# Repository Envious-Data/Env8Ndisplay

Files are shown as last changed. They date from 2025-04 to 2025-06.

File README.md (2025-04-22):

# Env8Ndisplay
 A 40x7 display using x4 is37fl3130

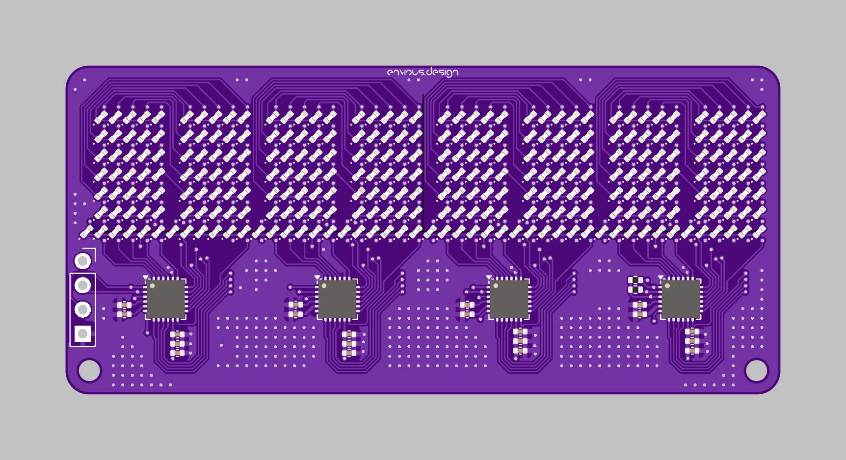
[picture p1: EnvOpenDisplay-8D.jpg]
Hello


## Info:
I designed a clock a while ago using 8x LTP-305s, LTP-305s and TIL-305s are both discontinued but I made a PCBA replica called DIY305, Ive also just put LEDs on a PCB in the same arangement which this repo is one of them.

I quite like character displays which is why I made this one, there is some demo code in the firmware folder that makes use of the pico SDK so wire it up to the a pico making sure VCC goes to 3V3 and not VBUS or VSYS unless you want to use a level shifter, a number of ICs can handle different logic level voltage if needed but this one tends to glitch out in my experience.

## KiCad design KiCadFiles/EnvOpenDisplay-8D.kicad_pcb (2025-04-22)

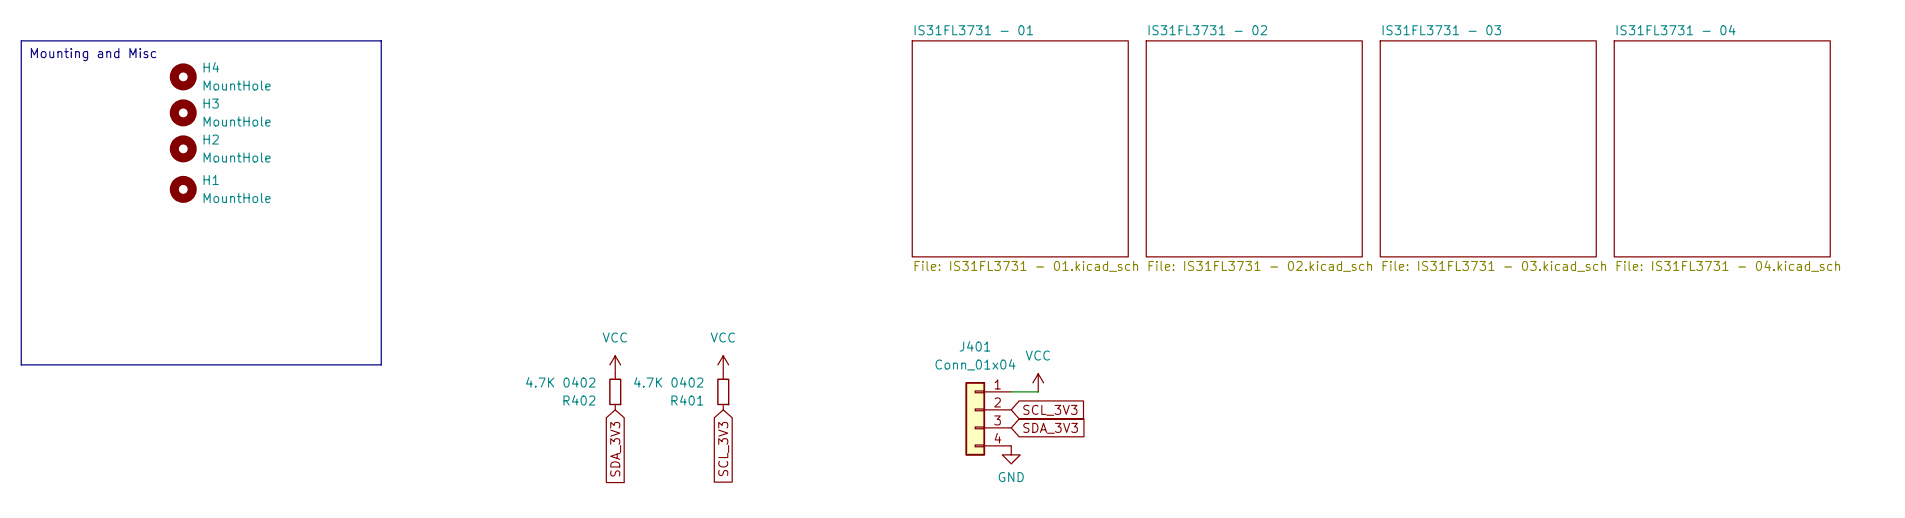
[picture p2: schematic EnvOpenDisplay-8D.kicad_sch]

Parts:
H1, H2, H3, H4: MountHole; MountingHole_2.2mm_M2
J401: Conn_01x04; PinSocket_1x04_P2.54mm_Vertical
R401, R402: 4.7K 0402; R_0402_1005Metric

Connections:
GND: J401.4; also elsewhere on the board
SCL_3V3: J401.2, R401.1; also elsewhere on the board
SDA_3V3: J401.3, R402.1; also elsewhere on the board
VCC: J401.1, R401.2, R402.2; also elsewhere on the board

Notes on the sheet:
Mounting and Misc

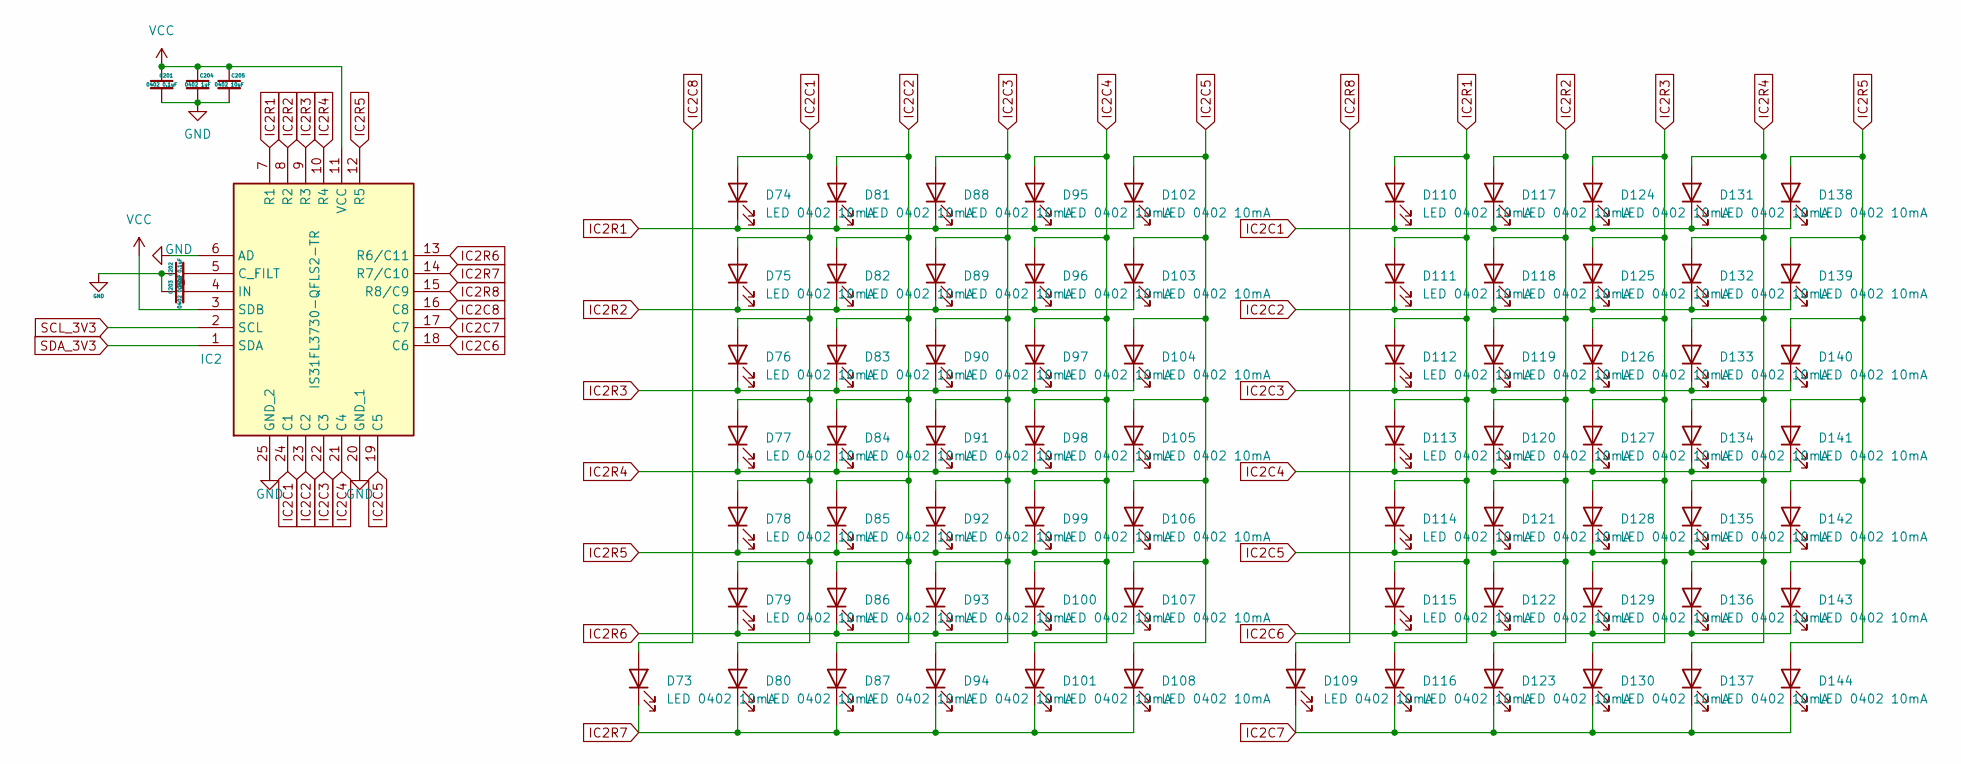
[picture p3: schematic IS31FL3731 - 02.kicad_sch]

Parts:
C201, C202: 0402 0.1uF; C_0402_1005Metric
C203: 0402 0.22uF; C_0402_1005Metric
C204: 0402 1uF; C_0402_1005Metric
C205: 0402 10uF; C_0402_1005Metric
D73, D74, D75, D76, D77, D78, D79, D80, D81, D82, D83, D84, D85, D86, D87, D88, D89, D90, D91, D92, D93, D94, D95, D96, D97, D98, D99, D100, D101, D102, D103, D104, D105, D106, D107, D108, D109, D110, D111, D112, D113, D114, D115, D116, D117, D118, D119, D120, D121, D122, D123, D124, D125, D126, D127, D128, D129, D130, D131, D132, D133, D134, D135, D136, D137, D138, D139, D140, D141, D142, D143, D144: LED 0402 10mA; LED_0402_1005Metric
IC2: IS31FL3730-QFLS2-TR; QFN-24-1EP_4x4mm_P0.5mm_EP2.6x2.6mm_ThermalVias; Mouser Part Number 870-IS31FL3730QFLS2R

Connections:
GND: C201.2, C202.1, C203.1, C204.2, C205.2, IC2.6 (AD), IC2.20 (GND_1), IC2.25 (GND_2); also elsewhere on the board
IC2C1: D74.2 (A), D75.2 (A), D76.2 (A), D77.2 (A), D78.2 (A), D79.2 (A), D80.2 (A), D110.1 (K), D117.1 (K), D124.1 (K), D131.1 (K), D138.1 (K), IC2.24 (C1)
IC2C2: D81.2 (A), D82.2 (A), D83.2 (A), D84.2 (A), D85.2 (A), D86.2 (A), D87.2 (A), D111.1 (K), D118.1 (K), D125.1 (K), D132.1 (K), D139.1 (K), IC2.23 (C2)
IC2C3: D88.2 (A), D89.2 (A), D90.2 (A), D91.2 (A), D92.2 (A), D93.2 (A), D94.2 (A), D112.1 (K), D119.1 (K), D126.1 (K), D133.1 (K), D140.1 (K), IC2.22 (C3)
IC2C4: D95.2 (A), D96.2 (A), D97.2 (A), D98.2 (A), D99.2 (A), D100.2 (A), D101.2 (A), D113.1 (K), D120.1 (K), D127.1 (K), D134.1 (K), D141.1 (K), IC2.21 (C4)
IC2C5: D102.2 (A), D103.2 (A), D104.2 (A), D105.2 (A), D106.2 (A), D107.2 (A), D108.2 (A), D114.1 (K), D121.1 (K), D128.1 (K), D135.1 (K), D142.1 (K), IC2.19 (C5)
IC2C6: D115.1 (K), D122.1 (K), D129.1 (K), D136.1 (K), D143.1 (K), IC2.18 (C6)
IC2C7: D109.1 (K), D116.1 (K), D123.1 (K), D130.1 (K), D137.1 (K), D144.1 (K), IC2.17 (C7)
IC2C8: D73.2 (A), IC2.16 (C8)
IC2R1: D74.1 (K), D81.1 (K), D88.1 (K), D95.1 (K), D102.1 (K), D110.2 (A), D111.2 (A), D112.2 (A), D113.2 (A), D114.2 (A), D115.2 (A), D116.2 (A), IC2.7 (R1)
IC2R2: D75.1 (K), D82.1 (K), D89.1 (K), D96.1 (K), D103.1 (K), D117.2 (A), D118.2 (A), D119.2 (A), D120.2 (A), D121.2 (A), D122.2 (A), D123.2 (A), IC2.8 (R2)
IC2R3: D76.1 (K), D83.1 (K), D90.1 (K), D97.1 (K), D104.1 (K), D124.2 (A), D125.2 (A), D126.2 (A), D127.2 (A), D128.2 (A), D129.2 (A), D130.2 (A), IC2.9 (R3)
IC2R4: D77.1 (K), D84.1 (K), D91.1 (K), D98.1 (K), D105.1 (K), D131.2 (A), D132.2 (A), D133.2 (A), D134.2 (A), D135.2 (A), D136.2 (A), D137.2 (A), IC2.10 (R4)
IC2R5: D78.1 (K), D85.1 (K), D92.1 (K), D99.1 (K), D106.1 (K), D138.2 (A), D139.2 (A), D140.2 (A), D141.2 (A), D142.2 (A), D143.2 (A), D144.2 (A), IC2.12 (R5)
IC2R6: D79.1 (K), D86.1 (K), D93.1 (K), D100.1 (K), D107.1 (K), IC2.13 (R6/C11)
IC2R7: D73.1 (K), D80.1 (K), D87.1 (K), D94.1 (K), D101.1 (K), D108.1 (K), IC2.14 (R7/C10)
IC2R8: D109.2 (A), IC2.15 (R8/C9)
unnamed: C202.2, IC2.5 (C_FILT)
unnamed: C203.2, IC2.4 (IN)
SCL_3V3: IC2.2 (SCL); also elsewhere on the board
SDA_3V3: IC2.1 (SDA); also elsewhere on the board
VCC: C201.1, C204.1, C205.1, IC2.3 (SDB), IC2.11 (VCC); also elsewhere on the board

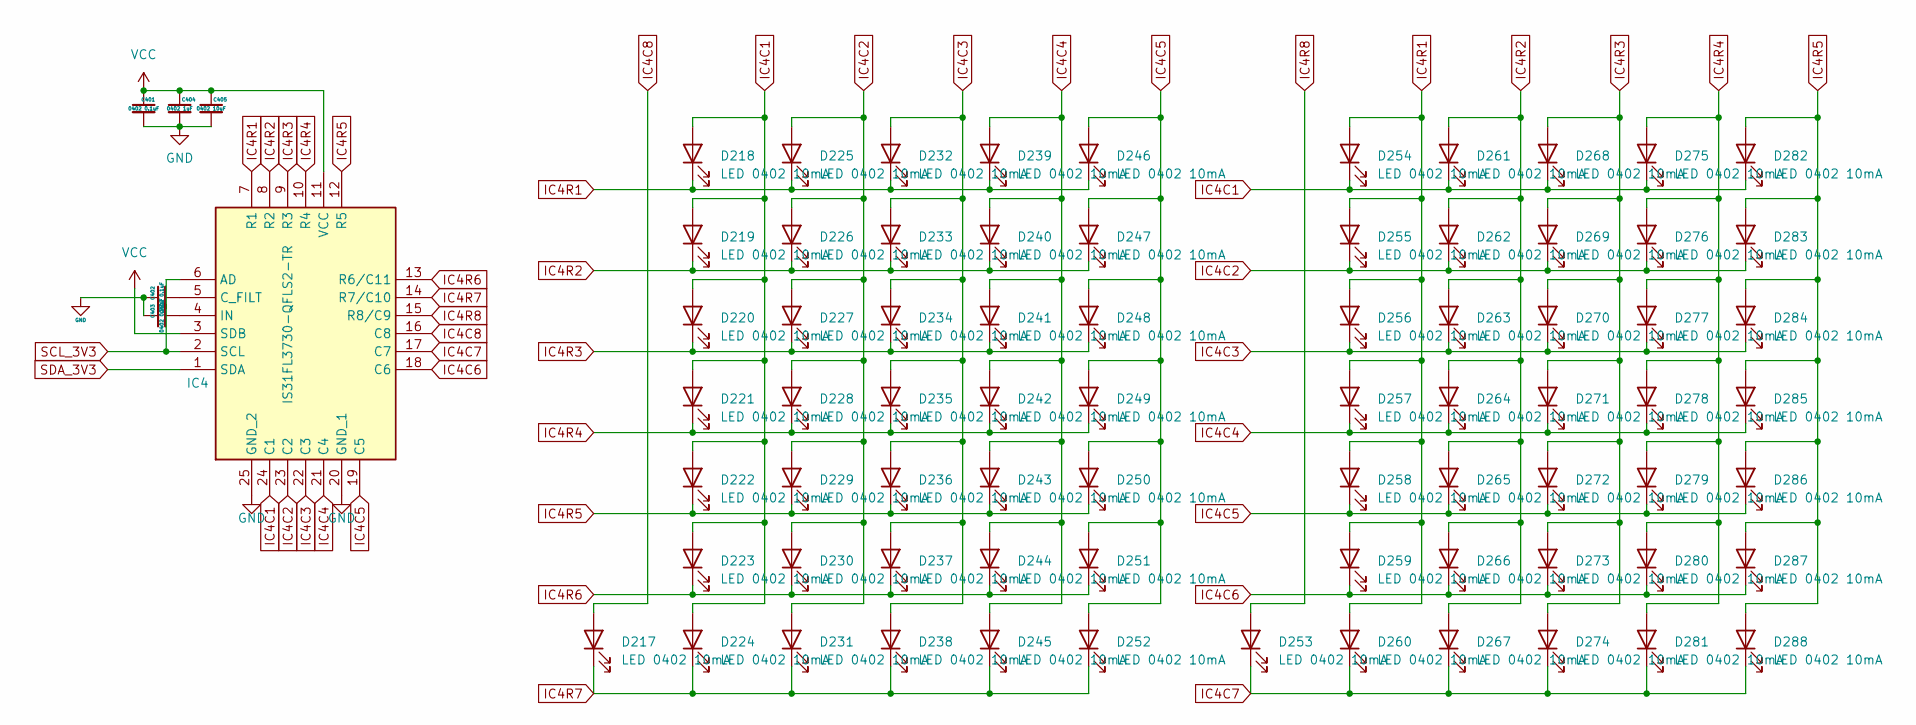
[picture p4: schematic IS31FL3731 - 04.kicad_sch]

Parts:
C401, C402: 0402 0.1uF; C_0402_1005Metric
C403: 0402 0.22uF; C_0402_1005Metric
C404: 0402 1uF; C_0402_1005Metric
C405: 0402 10uF; C_0402_1005Metric
D217, D218, D219, D220, D221, D222, D223, D224, D225, D226, D227, D228, D229, D230, D231, D232, D233, D234, D235, D236, D237, D238, D239, D240, D241, D242, D243, D244, D245, D246, D247, D248, D249, D250, D251, D252, D253, D254, D255, D256, D257, D258, D259, D260, D261, D262, D263, D264, D265, D266, D267, D268, D269, D270, D271, D272, D273, D274, D275, D276, D277, D278, D279, D280, D281, D282, D283, D284, D285, D286, D287, D288: LED 0402 10mA; LED_0402_1005Metric
IC4: IS31FL3730-QFLS2-TR; QFN-24-1EP_4x4mm_P0.5mm_EP2.6x2.6mm_ThermalVias; Mouser Part Number 870-IS31FL3730QFLS2R

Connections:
GND: C401.2, C402.1, C403.1, C404.2, C405.2, IC4.20 (GND_1), IC4.25 (GND_2); also elsewhere on the board
IC4C1: D218.2 (A), D219.2 (A), D220.2 (A), D221.2 (A), D222.2 (A), D223.2 (A), D224.2 (A), D254.1 (K), D261.1 (K), D268.1 (K), D275.1 (K), D282.1 (K), IC4.24 (C1)
IC4C2: D225.2 (A), D226.2 (A), D227.2 (A), D228.2 (A), D229.2 (A), D230.2 (A), D231.2 (A), D255.1 (K), D262.1 (K), D269.1 (K), D276.1 (K), D283.1 (K), IC4.23 (C2)
IC4C3: D232.2 (A), D233.2 (A), D234.2 (A), D235.2 (A), D236.2 (A), D237.2 (A), D238.2 (A), D256.1 (K), D263.1 (K), D270.1 (K), D277.1 (K), D284.1 (K), IC4.22 (C3)
IC4C4: D239.2 (A), D240.2 (A), D241.2 (A), D242.2 (A), D243.2 (A), D244.2 (A), D245.2 (A), D257.1 (K), D264.1 (K), D271.1 (K), D278.1 (K), D285.1 (K), IC4.21 (C4)
IC4C5: D246.2 (A), D247.2 (A), D248.2 (A), D249.2 (A), D250.2 (A), D251.2 (A), D252.2 (A), D258.1 (K), D265.1 (K), D272.1 (K), D279.1 (K), D286.1 (K), IC4.19 (C5)
IC4C6: D259.1 (K), D266.1 (K), D273.1 (K), D280.1 (K), D287.1 (K), IC4.18 (C6)
IC4C7: D253.1 (K), D260.1 (K), D267.1 (K), D274.1 (K), D281.1 (K), D288.1 (K), IC4.17 (C7)
IC4C8: D217.2 (A), IC4.16 (C8)
IC4R1: D218.1 (K), D225.1 (K), D232.1 (K), D239.1 (K), D246.1 (K), D254.2 (A), D255.2 (A), D256.2 (A), D257.2 (A), D258.2 (A), D259.2 (A), D260.2 (A), IC4.7 (R1)
IC4R2: D219.1 (K), D226.1 (K), D233.1 (K), D240.1 (K), D247.1 (K), D261.2 (A), D262.2 (A), D263.2 (A), D264.2 (A), D265.2 (A), D266.2 (A), D267.2 (A), IC4.8 (R2)
IC4R3: D220.1 (K), D227.1 (K), D234.1 (K), D241.1 (K), D248.1 (K), D268.2 (A), D269.2 (A), D270.2 (A), D271.2 (A), D272.2 (A), D273.2 (A), D274.2 (A), IC4.9 (R3)
IC4R4: D221.1 (K), D228.1 (K), D235.1 (K), D242.1 (K), D249.1 (K), D275.2 (A), D276.2 (A), D277.2 (A), D278.2 (A), D279.2 (A), D280.2 (A), D281.2 (A), IC4.10 (R4)
IC4R5: D222.1 (K), D229.1 (K), D236.1 (K), D243.1 (K), D250.1 (K), D282.2 (A), D283.2 (A), D284.2 (A), D285.2 (A), D286.2 (A), D287.2 (A), D288.2 (A), IC4.12 (R5)
IC4R6: D223.1 (K), D230.1 (K), D237.1 (K), D244.1 (K), D251.1 (K), IC4.13 (R6/C11)
IC4R7: D217.1 (K), D224.1 (K), D231.1 (K), D238.1 (K), D245.1 (K), D252.1 (K), IC4.14 (R7/C10)
IC4R8: D253.2 (A), IC4.15 (R8/C9)
unnamed: C402.2, IC4.5 (C_FILT)
unnamed: C403.2, IC4.4 (IN)
SCL_3V3: IC4.2 (SCL), IC4.6 (AD); also elsewhere on the board
SDA_3V3: IC4.1 (SDA); also elsewhere on the board
VCC: C401.1, C404.1, C405.1, IC4.3 (SDB), IC4.11 (VCC); also elsewhere on the board

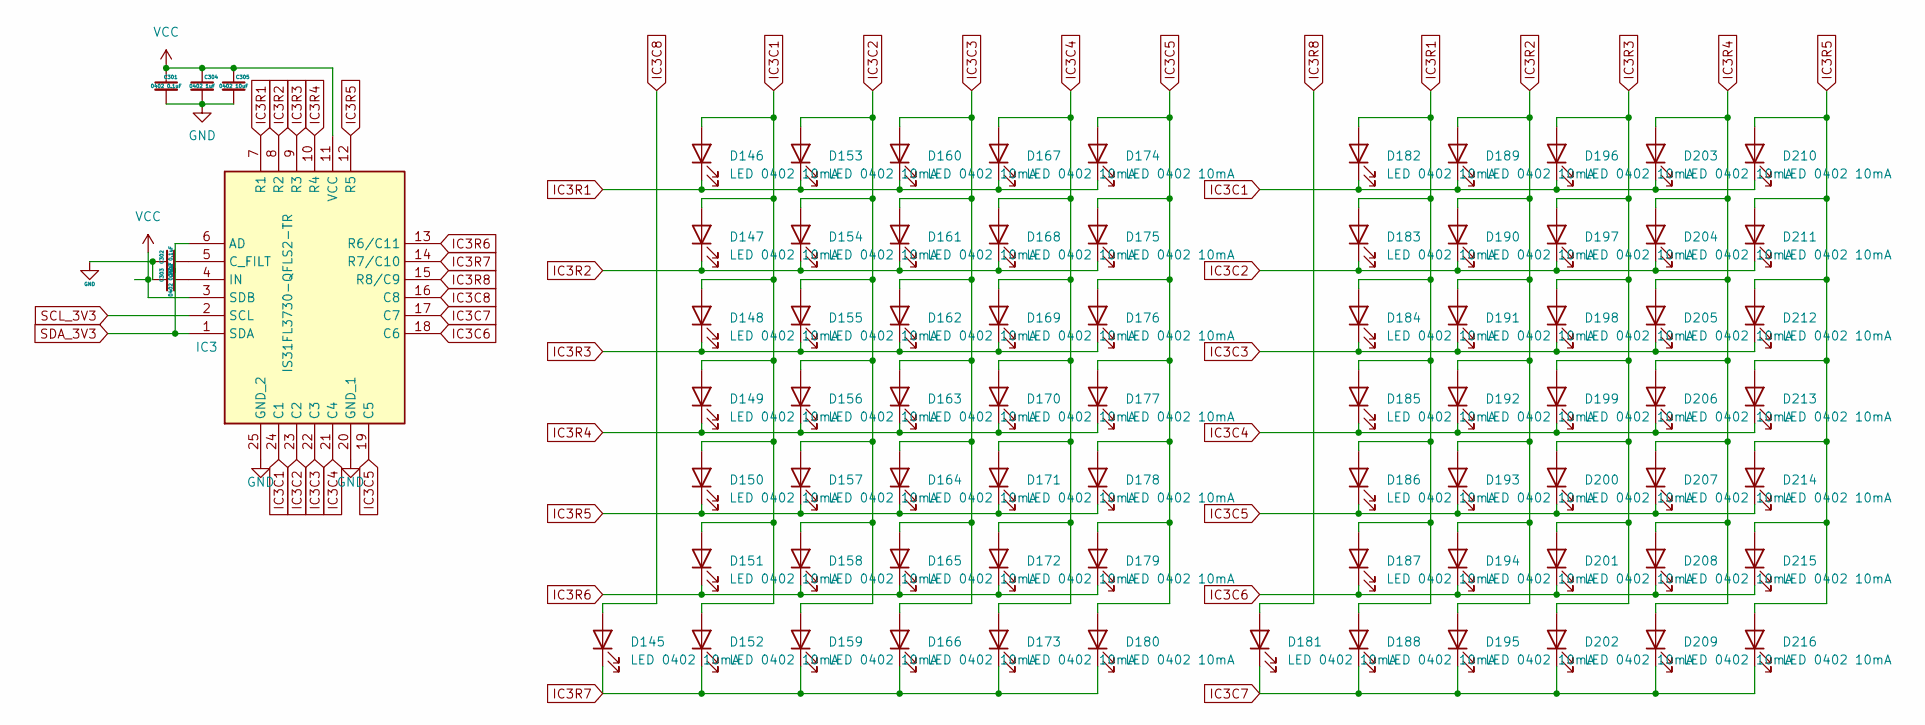
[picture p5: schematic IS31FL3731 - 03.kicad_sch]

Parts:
C301, C302: 0402 0.1uF; C_0402_1005Metric
C303: 0402 0.22uF; C_0402_1005Metric
C304: 0402 1uF; C_0402_1005Metric
C305: 0402 10uF; C_0402_1005Metric
D145, D146, D147, D148, D149, D150, D151, D152, D153, D154, D155, D156, D157, D158, D159, D160, D161, D162, D163, D164, D165, D166, D167, D168, D169, D170, D171, D172, D173, D174, D175, D176, D177, D178, D179, D180, D181, D182, D183, D184, D185, D186, D187, D188, D189, D190, D191, D192, D193, D194, D195, D196, D197, D198, D199, D200, D201, D202, D203, D204, D205, D206, D207, D208, D209, D210, D211, D212, D213, D214, D215, D216: LED 0402 10mA; LED_0402_1005Metric
IC3: IS31FL3730-QFLS2-TR; QFN-24-1EP_4x4mm_P0.5mm_EP2.6x2.6mm_ThermalVias; Mouser Part Number 870-IS31FL3730QFLS2R

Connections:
GND: C301.2, C302.1, C303.1, C304.2, C305.2, IC3.20 (GND_1), IC3.25 (GND_2); also elsewhere on the board
IC3C1: D146.2 (A), D147.2 (A), D148.2 (A), D149.2 (A), D150.2 (A), D151.2 (A), D152.2 (A), D182.1 (K), D189.1 (K), D196.1 (K), D203.1 (K), D210.1 (K), IC3.24 (C1)
IC3C2: D153.2 (A), D154.2 (A), D155.2 (A), D156.2 (A), D157.2 (A), D158.2 (A), D159.2 (A), D183.1 (K), D190.1 (K), D197.1 (K), D204.1 (K), D211.1 (K), IC3.23 (C2)
IC3C3: D160.2 (A), D161.2 (A), D162.2 (A), D163.2 (A), D164.2 (A), D165.2 (A), D166.2 (A), D184.1 (K), D191.1 (K), D198.1 (K), D205.1 (K), D212.1 (K), IC3.22 (C3)
IC3C4: D167.2 (A), D168.2 (A), D169.2 (A), D170.2 (A), D171.2 (A), D172.2 (A), D173.2 (A), D185.1 (K), D192.1 (K), D199.1 (K), D206.1 (K), D213.1 (K), IC3.21 (C4)
IC3C5: D174.2 (A), D175.2 (A), D176.2 (A), D177.2 (A), D178.2 (A), D179.2 (A), D180.2 (A), D186.1 (K), D193.1 (K), D200.1 (K), D207.1 (K), D214.1 (K), IC3.19 (C5)
IC3C6: D187.1 (K), D194.1 (K), D201.1 (K), D208.1 (K), D215.1 (K), IC3.18 (C6)
IC3C7: D181.1 (K), D188.1 (K), D195.1 (K), D202.1 (K), D209.1 (K), D216.1 (K), IC3.17 (C7)
IC3C8: D145.2 (A), IC3.16 (C8)
IC3R1: D146.1 (K), D153.1 (K), D160.1 (K), D167.1 (K), D174.1 (K), D182.2 (A), D183.2 (A), D184.2 (A), D185.2 (A), D186.2 (A), D187.2 (A), D188.2 (A), IC3.7 (R1)
IC3R2: D147.1 (K), D154.1 (K), D161.1 (K), D168.1 (K), D175.1 (K), D189.2 (A), D190.2 (A), D191.2 (A), D192.2 (A), D193.2 (A), D194.2 (A), D195.2 (A), IC3.8 (R2)
IC3R3: D148.1 (K), D155.1 (K), D162.1 (K), D169.1 (K), D176.1 (K), D196.2 (A), D197.2 (A), D198.2 (A), D199.2 (A), D200.2 (A), D201.2 (A), D202.2 (A), IC3.9 (R3)
IC3R4: D149.1 (K), D156.1 (K), D163.1 (K), D170.1 (K), D177.1 (K), D203.2 (A), D204.2 (A), D205.2 (A), D206.2 (A), D207.2 (A), D208.2 (A), D209.2 (A), IC3.10 (R4)
IC3R5: D150.1 (K), D157.1 (K), D164.1 (K), D171.1 (K), D178.1 (K), D210.2 (A), D211.2 (A), D212.2 (A), D213.2 (A), D214.2 (A), D215.2 (A), D216.2 (A), IC3.12 (R5)
IC3R6: D151.1 (K), D158.1 (K), D165.1 (K), D172.1 (K), D179.1 (K), IC3.13 (R6/C11)
IC3R7: D145.1 (K), D152.1 (K), D159.1 (K), D166.1 (K), D173.1 (K), D180.1 (K), IC3.14 (R7/C10)
IC3R8: D181.2 (A), IC3.15 (R8/C9)
unnamed: C302.2, IC3.5 (C_FILT)
unnamed: C303.2, IC3.4 (IN)
SCL_3V3: IC3.2 (SCL); also elsewhere on the board
SDA_3V3: IC3.1 (SDA), IC3.6 (AD); also elsewhere on the board
VCC: C301.1, C304.1, C305.1, IC3.3 (SDB), IC3.11 (VCC); also elsewhere on the board

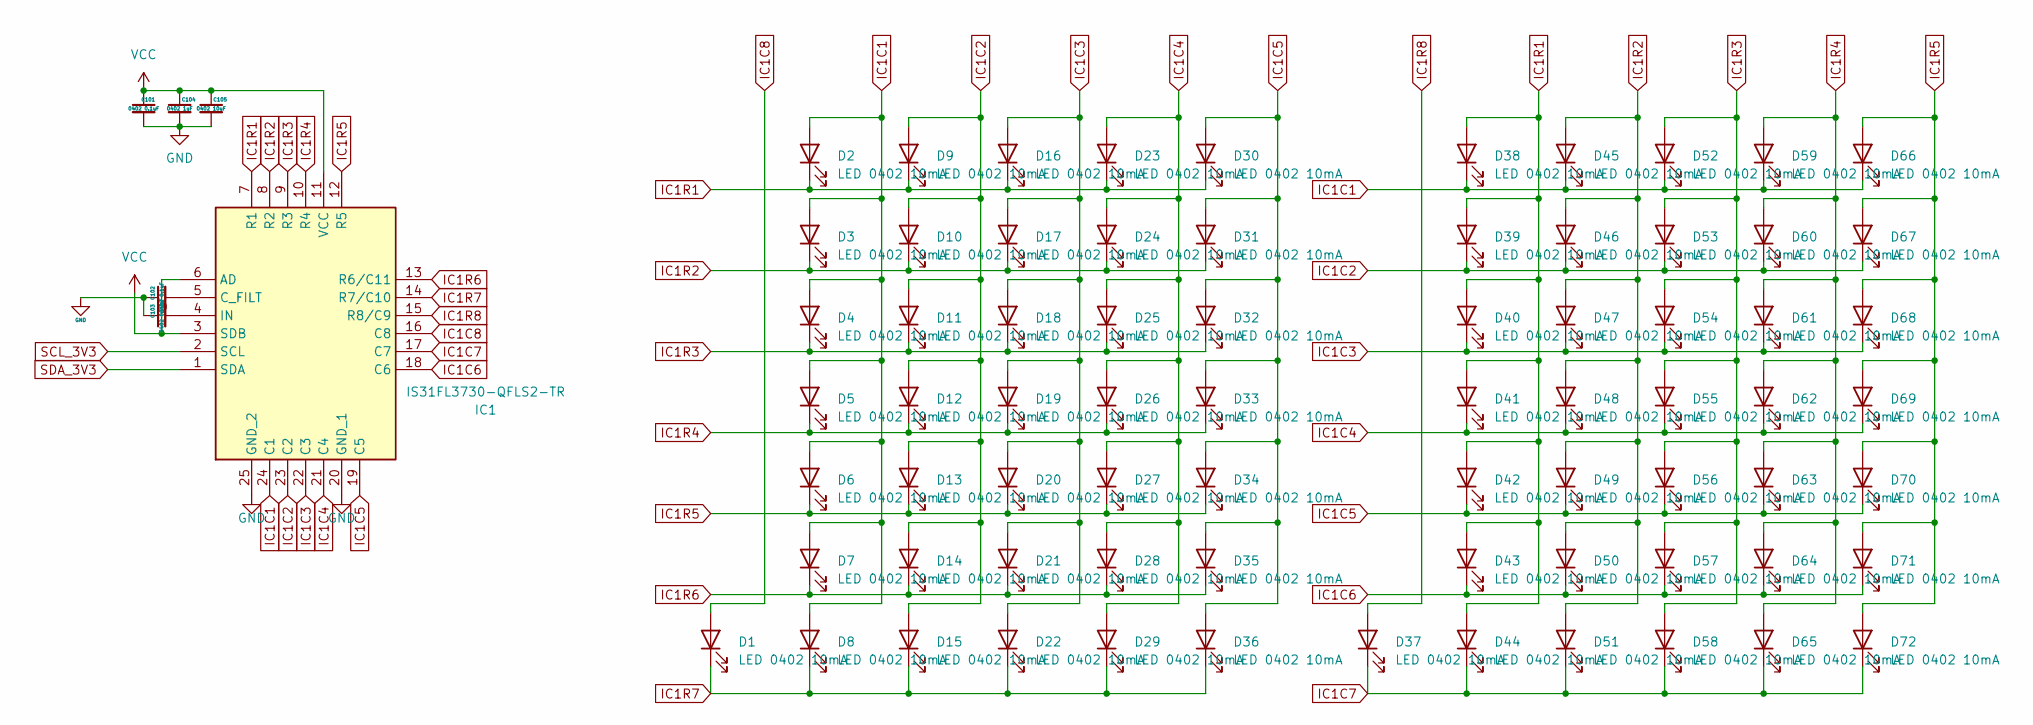
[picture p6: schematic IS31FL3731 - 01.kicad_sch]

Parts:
C101, C102: 0402 0.1uF; C_0402_1005Metric
C103: 0402 0.22uF; C_0402_1005Metric
C104: 0402 1uF; C_0402_1005Metric
C105: 0402 10uF; C_0402_1005Metric
D1, D2, D3, D4, D5, D6, D7, D8, D9, D10, D11, D12, D13, D14, D15, D16, D17, D18, D19, D20, D21, D22, D23, D24, D25, D26, D27, D28, D29, D30, D31, D32, D33, D34, D35, D36, D37, D38, D39, D40, D41, D42, D43, D44, D45, D46, D47, D48, D49, D50, D51, D52, D53, D54, D55, D56, D57, D58, D59, D60, D61, D62, D63, D64, D65, D66, D67, D68, D69, D70, D71, D72: LED 0402 10mA; LED_0402_1005Metric
IC1: IS31FL3730-QFLS2-TR; QFN-24-1EP_4x4mm_P0.5mm_EP2.6x2.6mm_ThermalVias; Mouser Part Number 870-IS31FL3730QFLS2R

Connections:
GND: C101.2, C102.1, C103.1, C104.2, C105.2, IC1.20 (GND_1), IC1.25 (GND_2); also elsewhere on the board
IC1C1: D2.2 (A), D3.2 (A), D4.2 (A), D5.2 (A), D6.2 (A), D7.2 (A), D8.2 (A), D38.1 (K), D45.1 (K), D52.1 (K), D59.1 (K), D66.1 (K), IC1.24 (C1)
IC1C2: D9.2 (A), D10.2 (A), D11.2 (A), D12.2 (A), D13.2 (A), D14.2 (A), D15.2 (A), D39.1 (K), D46.1 (K), D53.1 (K), D60.1 (K), D67.1 (K), IC1.23 (C2)
IC1C3: D16.2 (A), D17.2 (A), D18.2 (A), D19.2 (A), D20.2 (A), D21.2 (A), D22.2 (A), D40.1 (K), D47.1 (K), D54.1 (K), D61.1 (K), D68.1 (K), IC1.22 (C3)
IC1C4: D23.2 (A), D24.2 (A), D25.2 (A), D26.2 (A), D27.2 (A), D28.2 (A), D29.2 (A), D41.1 (K), D48.1 (K), D55.1 (K), D62.1 (K), D69.1 (K), IC1.21 (C4)
IC1C5: D30.2 (A), D31.2 (A), D32.2 (A), D33.2 (A), D34.2 (A), D35.2 (A), D36.2 (A), D42.1 (K), D49.1 (K), D56.1 (K), D63.1 (K), D70.1 (K), IC1.19 (C5)
IC1C6: D43.1 (K), D50.1 (K), D57.1 (K), D64.1 (K), D71.1 (K), IC1.18 (C6)
IC1C7: D37.1 (K), D44.1 (K), D51.1 (K), D58.1 (K), D65.1 (K), D72.1 (K), IC1.17 (C7)
IC1C8: D1.2 (A), IC1.16 (C8)
IC1R1: D2.1 (K), D9.1 (K), D16.1 (K), D23.1 (K), D30.1 (K), D38.2 (A), D39.2 (A), D40.2 (A), D41.2 (A), D42.2 (A), D43.2 (A), D44.2 (A), IC1.7 (R1)
IC1R2: D3.1 (K), D10.1 (K), D17.1 (K), D24.1 (K), D31.1 (K), D45.2 (A), D46.2 (A), D47.2 (A), D48.2 (A), D49.2 (A), D50.2 (A), D51.2 (A), IC1.8 (R2)
IC1R3: D4.1 (K), D11.1 (K), D18.1 (K), D25.1 (K), D32.1 (K), D52.2 (A), D53.2 (A), D54.2 (A), D55.2 (A), D56.2 (A), D57.2 (A), D58.2 (A), IC1.9 (R3)
IC1R4: D5.1 (K), D12.1 (K), D19.1 (K), D26.1 (K), D33.1 (K), D59.2 (A), D60.2 (A), D61.2 (A), D62.2 (A), D63.2 (A), D64.2 (A), D65.2 (A), IC1.10 (R4)
IC1R5: D6.1 (K), D13.1 (K), D20.1 (K), D27.1 (K), D34.1 (K), D66.2 (A), D67.2 (A), D68.2 (A), D69.2 (A), D70.2 (A), D71.2 (A), D72.2 (A), IC1.12 (R5)
IC1R6: D7.1 (K), D14.1 (K), D21.1 (K), D28.1 (K), D35.1 (K), IC1.13 (R6/C11)
IC1R7: D1.1 (K), D8.1 (K), D15.1 (K), D22.1 (K), D29.1 (K), D36.1 (K), IC1.14 (R7/C10)
IC1R8: D37.2 (A), IC1.15 (R8/C9)
unnamed: C102.2, IC1.5 (C_FILT)
unnamed: C103.2, IC1.4 (IN)
SCL_3V3: IC1.2 (SCL); also elsewhere on the board
SDA_3V3: IC1.1 (SDA); also elsewhere on the board
VCC: C101.1, C104.1, C105.1, IC1.3 (SDB), IC1.6 (AD), IC1.11 (VCC); also elsewhere on the board

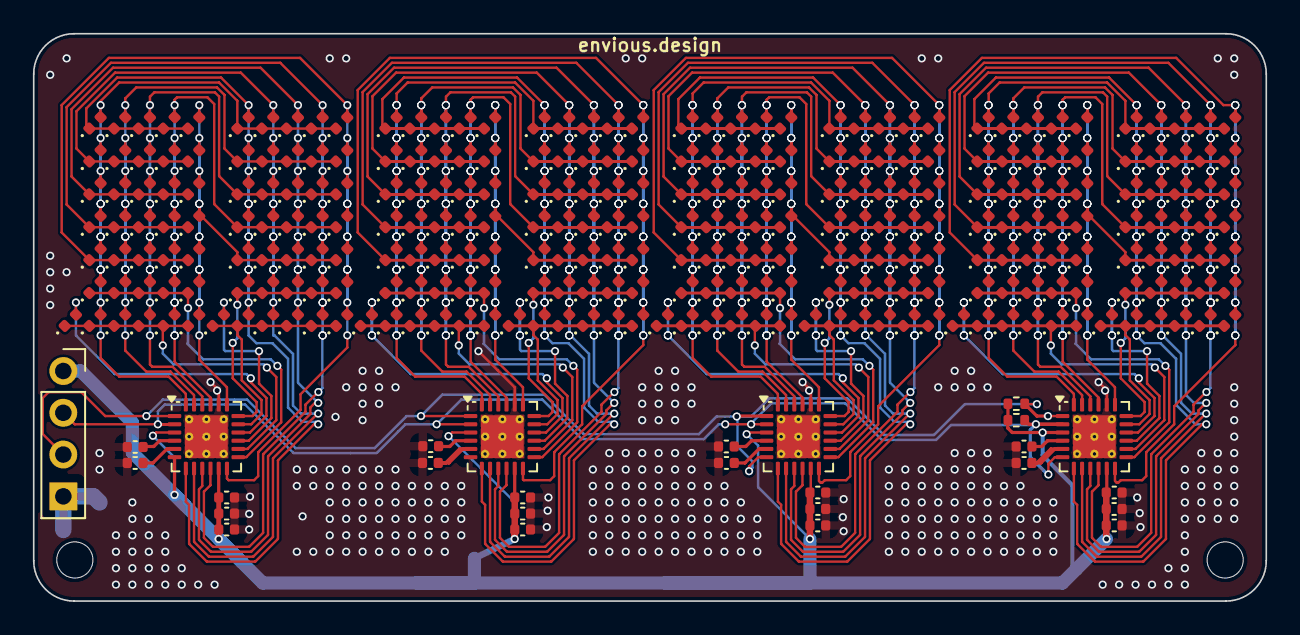
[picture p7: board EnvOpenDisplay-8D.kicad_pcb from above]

Board: 2 copper layers, 75.0 x 34.5 mm, 317 parts (0 on the bottom side), 76 nets.

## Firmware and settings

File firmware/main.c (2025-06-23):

#include "pico/stdlib.h"
#include "pico/multicore.h"
#include "is31fl3730_display.h" // Display code handles I2C init
#include "hardware/uart.h"       // Still useful for general UART functions if needed, but stdio_usb handles USB serial
#include "hardware/gpio.h"
#include "hardware/sync.h"
// #include "hardware/i2c.h" // No longer explicitly needed here as display code handles it, and ds3231 also uses it
#include <stdio.h>
#include <string.h>
#include "ds3231.h" // Assuming this contains clock_read_time, clock_set_time, bcd_to_int, int_to_bcd, and clock_buffer

// For the BOOTSEL button functionality
#include "hardware/structs/ioqspi.h"
#include "hardware/structs/sio.h"

// Define the buffer size for serial input
#define SERIAL_BUFFER_SIZE 32

// Global buffer for serial input (single writer, single reader on core 1)
char serial_data_buffer[SERIAL_BUFFER_SIZE];

// Enum for display modes
typedef enum {
    MODE_CLOCK,
    MODE_DATE,
    MODE_EXAMPLE_STRING,
    NUM_MODES // Keep this last to easily get the number of modes
} DisplayMode;

// Global variable to store the current display mode
volatile DisplayMode current_display_mode = MODE_CLOCK;

// Global variable to store the arbitrary string for example mode
char example_string[9] = " 8nDisp "; // Max 8 characters for display, plus null terminator

// Function to parse the time string and set the RTC
void set_rtc_from_string(const char* time_str) {
    int year, month, day, hour, minute, second;
    // Expected format:YYYY-MM-DD HH:MM:SS
    if (sscanf(time_str, "%d-%d-%d %d:%d:%d", &year, &month, &day, &hour, &minute, &second) == 6) {
        printf("Attempting to set RTC to: %04d-%02d-%02d %02d:%02d:%02d\n", year, month, day, hour, minute, second);

        // Convert integers to BCD before calling clock_set_time
        unsigned char bcd_second = int_to_bcd(second);
        unsigned char bcd_minute = int_to_bcd(minute);
        unsigned char bcd_hour = int_to_bcd(hour);
        unsigned char bcd_day = int_to_bcd(day);
        unsigned char bcd_month = int_to_bcd(month);
        unsigned char bcd_year = int_to_bcd(year % 100); // DS3231 stores 2-digit year (00-99)

        clock_set_time(bcd_second, bcd_minute, bcd_hour, bcd_day, bcd_month, bcd_year);
        printf("RTC set command issued.\n");
    } else {
        printf("Invalid time string format received: %s. Expected YYYY-MM-DD HH:MM:SS\n", time_str);
    }
}

// Function to set the example string from serial input
void set_example_string_from_string(const char* str) {
    // Ensure the string fits and is null-terminated
    strncpy(example_string, str, sizeof(example_string) - 1);
    example_string[sizeof(example_string) - 1] = '\0';
    printf("Example string set to: \"%s\"\n", example_string);
}


// BOOTSEL button functionality
bool __no_inline_not_in_flash_func(get_bootsel_button)() {
    const uint CS_PIN_INDEX = 1;

    // Must disable interrupts, as interrupt handlers may be in flash, and we
    // are about to temporarily disable flash access!
    uint32_t flags = save_and_disable_interrupts();

    // Set chip select to Hi-Z
    hw_write_masked(&ioqspi_hw->io[CS_PIN_INDEX].ctrl,
                    GPIO_OVERRIDE_LOW << IO_QSPI_GPIO_QSPI_SS_CTRL_OEOVER_LSB,
                    IO_QSPI_GPIO_QSPI_SS_CTRL_OEOVER_BITS);

    // Note we can't call into any sleep functions in flash right now
    for (volatile int i = 0; i < 1000; ++i);

    // The HI GPIO registers in SIO can observe and control the 6 QSPI pins.
    // Note the button pulls the pin *low* when pressed.
#if PICO_RP2040
    #define CS_BIT (1u << 1)
#else
    #define CS_BIT SIO_GPIO_HI_IN_QSPI_CSN_BITS
#endif
    bool button_state = !(sio_hw->gpio_hi_in & CS_BIT);

    // Need to restore the state of chip select, else we are going to have a
    // bad time when we return to code in flash!
    hw_write_masked(&ioqspi_hw->io[CS_PIN_INDEX].ctrl,
                    GPIO_OVERRIDE_NORMAL << IO_QSPI_GPIO_QSPI_SS_CTRL_OEOVER_LSB,
                    IO_QSPI_GPIO_QSPI_SS_CTRL_OEOVER_BITS);

    restore_interrupts(flags);

    return button_state;
}

void core1_entry() {
    // Clear the buffer once at startup for Core 1
    memset(serial_data_buffer, 0, SERIAL_BUFFER_SIZE);
    size_t current_buffer_len = 0; // Keep track of current length

    while (true) {
        if (stdio_usb_connected()) {
            int received_char = getchar_timeout_us(0); // Non-blocking read

            if (received_char != PICO_ERROR_TIMEOUT && received_char != EOF) {
                if (received_char == '\n' || received_char == '\r') {
                    // Null-terminate the string
                    serial_data_buffer[current_buffer_len] = '\0';

                    // Check for commands
                    if (strncmp(serial_data_buffer, "settime ", 8) == 0) {
                        // Extract the time string (skip "settime ")
                        set_rtc_from_string(serial_data_buffer + 8);
                    } else if (strncmp(serial_data_buffer, "setexample ", 11) == 0) {
                        // Extract the example string (skip "setexample ")
                        set_example_string_from_string(serial_data_buffer + 11);
                    }
                    else {
                        printf("Unknown command received: %s\n", serial_data_buffer);
                    }

                    // Clear the buffer for the next command
                    memset(serial_data_buffer, 0, SERIAL_BUFFER_SIZE);
                    current_buffer_len = 0; // Reset length
                } else if (current_buffer_len < SERIAL_BUFFER_SIZE - 1) {
                    // Append character to buffer if not full and not a newline/carriage return
                    serial_data_buffer[current_buffer_len++] = (char)received_char;
                } else {
                    // Buffer is full, discard new characters until newline/carriage return
                    printf("Serial buffer full, discarding character: %c\n", (char)received_char);
                }
            }
        }
        sleep_ms(1); // Small delay to prevent busy-waiting
    }
}

int main() {
    // Initialize stdio with USB
    stdio_init_all();
    printf("USB Serial Started!\n");
    sleep_ms(1);

    // Initialize the display. This function is assumed to handle I2C initialization internally.
    // Since is31fl3730_display.c and ds3231.c both use i2c1 on the same pins,
    // initializing it once here is sufficient.
    init_display();
    printf("Display Init\n");

    // --- Start Display Driver Demonstration ---
    printf("Starting display driver demonstration...\n");
    clear_all(true);
    sleep_ms(500);

    // 1. Welcome Message
    display_string("STARTING");
    sleep_ms(250);
    clear_all(true);
    sleep_ms(250);

    // 2. Pixel by Pixel - Fill all matrices in logical order
    printf("Demonstrating individual pixels (filling all matrices in logical order)...\n");
    for (int logical_idx = 0; logical_idx < 8; logical_idx++) { // Iterate through all 8 logical displays
        int physical_idx = display_map[logical_idx]; // Get the physical index from the map
        int chip_idx = physical_idx / 2; // Calculate chip index
        int matrix_type = physical_idx % 2; // Calculate matrix type (A or B)

        printf("Filling Logical Display %d (Chip %d, Matrix Type %d)...\n", logical_idx, chip_idx, matrix_type);
        for (int i = 0; i < 8; i++) {
            for (int j = 0; j < 8; j++) {
                set_pixel(chip_idx, matrix_type, i, j, true); // Set pixel on the determined chip and matrix
                update_display();
                //sleep_ms(); // Faster fill for all matrices
            }
        }
        //sleep_ms(1);
        //clear_chip_matrix(chip_idx, matrix_type); // Clear current matrix
        update_display();
        sleep_ms(1);
    }
    sleep_ms(250);
    clear_all(true); // Ensure everything is clear after the demo
    sleep_ms(250);


    // 4. Scrolling Message
    printf("Demonstrating scrolling string...\n");
    scroll_display_string("PICO CLOCK DEMO! ");
    sleep_ms(250);
    scroll_display_string("Envious.Designs - EnvOpenClock - 8nDisp");
    sleep_ms(250);

    // 5. Static Message with characters
    printf("Displaying static characters...\n");
    display_string("PICO!");
    sleep_ms(250);
    clear_all(true);
    sleep_ms(250);

    printf("Display driver demonstration finished.\n");
    // --- End Display Driver Demonstration ---

    // Launch the second core
    multicore_launch_core1(core1_entry);
    printf("Multicore launched\n");

    bool prev_bootsel_state = false; // To detect rising edge (button release)
    uint64_t last_button_press_time = 0;
    const uint64_t DEBOUNCE_DELAY_MS = 200; // 200ms debounce

    // Core 0 loop for displaying time and handling mode changes
    char display_buffer[9]; // HH:MM:SS\0 or DD-MM-YY\0 or 8 chars + null

    while (true) {
        // --- BOOTSEL Button Handling ---
        bool current_bootsel_state = get_bootsel_button();
        uint64_t current_time_ms = to_ms_since_boot(get_absolute_time());

        // Check for a *release* of the button to trigger mode change
        // This makes it less sensitive to accidental presses and acts on button "click"
        if (!current_bootsel_state && prev_bootsel_state && (current_time_ms - last_button_press_time > DEBOUNCE_DELAY_MS)) {
            // Button released (falling edge) and debounced
            current_display_mode = (current_display_mode + 1) % NUM_MODES;
            printf("Mode changed to: ");
            switch (current_display_mode) {
                case MODE_CLOCK: printf("CLOCK\n"); break;
                case MODE_DATE: printf("DATE\n"); break;
                case MODE_EXAMPLE_STRING: printf("EXAMPLE STRING\n"); break;
                default: printf("UNKNOWN\n"); break;
            }
            last_button_press_time = current_time_ms; // Update last press time
        }
        prev_bootsel_state = current_bootsel_state; // Update previous state

        // --- Display Logic based on Mode ---
        clock_read_time(); // Always read time to keep it updated internally

        // Get RTC data using bcd_to_int and correct clock_buffer indices
        unsigned char hour = bcd_to_int(clock_buffer[2]);
        unsigned char minute = bcd_to_int(clock_buffer[1]);
        unsigned char second = bcd_to_int(clock_buffer[0]);
        unsigned char day = bcd_to_int(clock_buffer[4]);   // Day of month
        unsigned char month = bcd_to_int(clock_buffer[5]); // Month
        unsigned char year = bcd_to_int(clock_buffer[6]);  // Year

        switch (current_display_mode) {
            case MODE_CLOCK:
                // Format the time as HH:MM:SS
                snprintf(display_buffer, sizeof(display_buffer), "%02d:%02d:%02d", hour, minute, second);
                break;
            case MODE_DATE:
                // Format the date as DD-MM-YY
                snprintf(display_buffer, sizeof(display_buffer), "%02d-%02d-%02d", day, month, year);
                break;
            case MODE_EXAMPLE_STRING:
                // Display the arbitrary string
                strncpy(display_buffer, example_string, sizeof(display_buffer) - 1);
                display_buffer[sizeof(display_buffer) - 1] = '\0'; // Ensure null termination
                break;
            default:
                strncpy(display_buffer, "ERROR   ", sizeof(display_buffer)); // Fallback
                break;
        }

        // Display the string on the LED matrices
        display_string(display_buffer);

        // Print to serial for debugging (optional)
        printf("Current Display: %s (Mode: %d)\n", display_buffer, current_display_mode);

        sleep_ms(100); // Update display and check button every 100ms
    }

    return 0;
}

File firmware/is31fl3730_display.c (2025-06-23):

// is31fl3730_display.c
#include "is31fl3730_display.h"
#include <stdint.h>
#include <string.h>
#include <stdlib.h>
#include <stdio.h>
#include "hardware/gpio.h"
#include "hardware/i2c.h"
#include "pico/stdlib.h"
#include <math.h>
#include <stdbool.h>

#define I2C_DISPLAY_LINE i2c1
#define I2C_DISPLAY_SDA 14
#define I2C_DISPLAY_SCL 15

#define MODE_ADDR 0b00000000
#define BRIGHTNESS_ADDR  0b00011001
#define BRIGHTNESS_VALUE     0b000000100
#define UPDATE_ADDR 0b00001100
#define OPTION_ADDR 0b00001101
#define MATRIX_A_ADDR 0b00001110 // Corresponds to Python's CMD_MATRIX_2 (0x0E)
#define MATRIX_B_ADDR 0b00000001 // Corresponds to Python's CMD_MATRIX_1 (0x01)

#define DEFAULT_MODE 0b00011000
#define DEFAULT_OPTIONS 0b00001110

// Added defines from Python code
#define CMD_BRIGHTNESS 0x19
#define CMD_MODE 0x00
#define CMD_UPDATE 0x0C
#define CMD_OPTIONS 0x0D
#define CMD_MATRIX_1 0x01 // Corresponds to MATRIX_B_ADDR
#define CMD_MATRIX_2 0x0E // Corresponds to MATRIX_A_ADDR

#define MATRIX_TYPE_A 0 // Used to differentiate between the two matrices on a single chip
#define MATRIX_TYPE_B 1

uint8_t addresses[4] = {0x60, 0x62, 0x61, 0x63}; // Adjusted for 4 chips

uint8_t displays[8][8] = {{0}}; // displays[physical_index][row_data]

const int display_map[8] = {
    6, // Logical 0 -> Physical 6
    7, // Logical 1 -> Physical 7
    0, // Logical 2 -> Physical 0
    1, // Logical 3 -> Physical 1
    2, // Logical 4 -> Physical 2
    3, // Logical 5 -> Physical 3
    4, // Logical 6 -> Physical 4
    5  // Logical 7 -> Physical 5
};

// In your is31fl3730_display.c file, perhaps globally:
uint8_t char_index_map[128] = {0}; // Initialize all to 0 (for space or error)

void populate_char_index_map() {
    char_index_map[' '] = 0;
    char_index_map['!'] = 1;
    char_index_map['"'] = 2;
    char_index_map['#'] = 3;
    char_index_map['$'] = 4;
    char_index_map['%'] = 5;
    char_index_map['&'] = 6;
    char_index_map['\''] = 7;
    char_index_map['('] = 8;
    char_index_map[')'] = 9;
    char_index_map['*'] = 10;
    char_index_map['+'] = 11;
    char_index_map[','] = 12;
    char_index_map['-'] = 13;
    char_index_map['.'] = 14;
    char_index_map['/'] = 15;
    char_index_map['0'] = 16;
    char_index_map['1'] = 17;
    char_index_map['2'] = 18;
    char_index_map['3'] = 19;
    char_index_map['4'] = 20;
    char_index_map['5'] = 21;
    char_index_map['6'] = 22;
    char_index_map['7'] = 23;
    char_index_map['8'] = 24;
    char_index_map['9'] = 25;
    char_index_map[':'] = 26;
    char_index_map[';'] = 27;
    char_index_map['<'] = 28;
    char_index_map['='] = 29;
    char_index_map['>'] = 30;
    char_index_map['?'] = 31;
    char_index_map['@'] = 32;
    char_index_map['A'] = 33;
    char_index_map['B'] = 34;
    char_index_map['C'] = 35;
    char_index_map['D'] = 36;
    char_index_map['E'] = 37;
    char_index_map['F'] = 38;
    char_index_map['G'] = 39;
    char_index_map['H'] = 40;
    char_index_map['I'] = 41;
    char_index_map['J'] = 42;
    char_index_map['K'] = 43;
    char_index_map['L'] = 44;
    char_index_map['M'] = 45;
    char_index_map['N'] = 46;
    char_index_map['O'] = 47;
    char_index_map['P'] = 48;
    char_index_map['Q'] = 49;
    char_index_map['R'] = 50;
    char_index_map['S'] = 51;
    char_index_map['T'] = 52;
    char_index_map['U'] = 53;
    char_index_map['V'] = 54;
    char_index_map['W'] = 55;
    char_index_map['X'] = 56;
    char_index_map['Y'] = 57;
    char_index_map['Z'] = 58;
    char_index_map['a'] = 59;
    char_index_map['b'] = 60;
    char_index_map['c'] = 61;
    char_index_map['d'] = 62;
    char_index_map['e'] = 63;
    char_index_map['f'] = 64;
    char_index_map['g'] = 65;
    char_index_map['h'] = 66;
    char_index_map['i'] = 67;
    char_index_map['j'] = 68;
    char_index_map['k'] = 69;
    char_index_map['l'] = 70;
    char_index_map['m'] = 71;
    char_index_map['n'] = 72;
    char_index_map['o'] = 73;
    char_index_map['p'] = 74;
    char_index_map['q'] = 75;
    char_index_map['r'] = 76;
    char_index_map['s'] = 77;
    char_index_map['t'] = 78;
    char_index_map['u'] = 79;
    char_index_map['v'] = 80;
    char_index_map['w'] = 81;
    char_index_map['x'] = 82;
    char_index_map['y'] = 83;
    char_index_map['z'] = 84;
}
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
